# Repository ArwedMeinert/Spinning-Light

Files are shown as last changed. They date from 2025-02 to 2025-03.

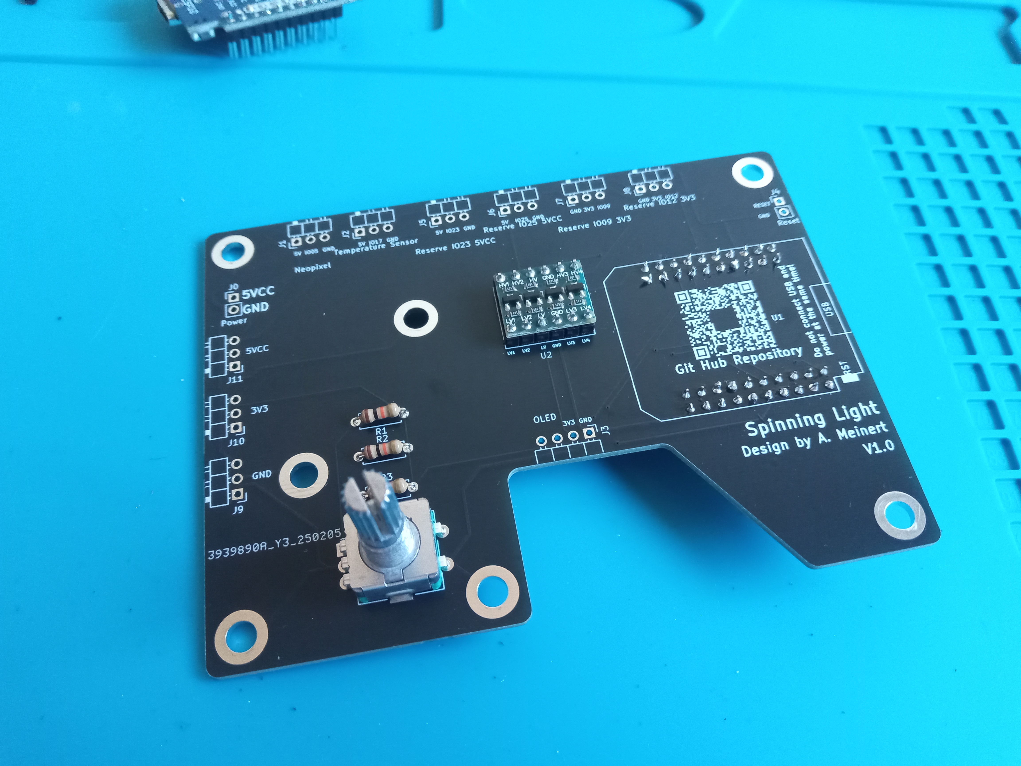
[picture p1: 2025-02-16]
Pictures/PCB with some parts.jpg

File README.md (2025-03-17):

# Spinning Light

___  
This project combines dynamic RGB lighting with a home trainer to enhance your workout experience. The lamp pairs with a power trainer, mapping your power output to its LEDs. The displayed color corresponds to different zones based on your set FTP value. During sprints, the LEDs flash red and yellow to motivate you in your "pain cave."  

All parameters—such as LED brightness, FTP value, and the power trainer’s Bluetooth address—can be adjusted via the GUI. Under **Advanced Settings**, you can modify the zone percentages, LED filter constants, and the number of pixels.  
___  
On the main screen, sensor data for humidity and temperature is displayed. The second page shows the current power output, while the third page displays the Bluetooth address and the power trainer's name.
___
Check out the Youtube Video about the project:

Watch the demo (https://www.youtube.com/watch?v=y7wqykNJxKs)
---

# Microcontroller and Code

The lamp is built around an ESP32 NodeMCU Mini to keep the design compact. The firmware was developed using the Arduino IDE with the ESP32 board definitions (select Node32s). The encoder’s built-in push button is handled without an interrupt, which improves performance and reduces false button detections. A physical pull-up resistor is used, so the internal pull-up is disabled on that pin.

## Connecting Bluetooth

Bluetooth Low Energy (BTLE) is used for connectivity, with the necessary library included in the sketch. Ideally, the device writes the trainer’s address to the EEPROM for automatic reconnection on subsequent startups. However, while the ESP can reconnect automatically after a trainer is initially connected, it does not do so after a restart and must search for the trainer again. Once connected, the ESP subscribes to the power service of the trainer and receives its power data, which is then mapped to LED colors.

---

# Casing

The casing is designed for modularity. Openings for the display, encoder, temperature sensor, and USB port can be finalized after printing. This also allows you to hardcode the Bluetooth address if you prefer not to use the GUI.

Exploded view

---

# PCB



The PCB is designed to work with DuPont connectors for all external components. The ESP is mounted on the back to leave space for the casing lid. The ESP's USB-C port is positioned to allow external access if the plastic cover is removed. The board can be powered either via USB or through the 5V connector located in the left opening. The encoder is mounted directly on the PCB and uses three pull-up resistors—two for rotation detection and one for the push button.

Not all supports need to be screwed in; they primarily help stabilize the push button and prevent the PCB from bending under pressure.



---

# Assembly

The temperature sensor is secured to the left side of the casing. To ensure a proper fit, a section of the lid must be removed to allow the sensor's PCB to protrude. The sensor is mounted using M2 screws, fastened from the outside with a nut on the opposite side. This step should be completed first.

Next, insert the screws into the standoff holes. Use at least four screws to secure the PCB; the remaining standoffs primarily support the encoder’s push button. Once the PCB is fixed within the casing, connect the 5V supply if necessary—or use the USB port for power.



Prepare the lid by removing the sections designated for I/O components (the square for the screen and the circle for the encoder). The OLED screen should be equipped with a DuPont connector and then screwed in place. It doesn't matter whether the screen is mounted on the lid or underneath it; however, if it is mounted below, ensure it is properly supported to avoid damage.

Finally, attach the LED profile to the top, ensuring that the cable is routed into the casing. Depending on the LEDs used, prepare the cables according to the PCB's silkscreen guidelines. Once the lid is modified and the connectors are attached, carefully install the lid to avoid interfering with the sensor and encoder. Finally, secure the lid with screws, and your setup should be operational.



## Bill Of Material (BoM)

<details>
  <summary>Click to expand</summary>

| #  | Reference | Qty | Value | Footprint | DNP |
|----|---|-----|---|---|-----|
| 1  | J0 | 1 | Power | Connector_PinHeader_2.54mm:PinHeader_1x02_P2.54mm_Vertical | |
| 2  | J1 | 1 | Neopixel | Connector_PinHeader_2.54mm:PinHeader_1x03_P2.54mm_Horizontal | |
| 3  | J2 | 1 | Temperature Sensor | Connector_PinHeader_2.54mm:PinHeader_1x03_P2.54mm_Horizontal | |
| 4  | J3 | 1 | OLED | Connector_PinHeader_2.54mm:PinHeader_1x04_P2.54mm_Horizontal | |
| 5  | J4 | 1 | Reset | Connector_PinHeader_2.54mm:PinHeader_1x02_P2.54mm_Vertical | |
| 6  | J5 | 1 | Reserve IO23 5VCC | Connector_PinHeader_2.54mm:PinHeader_1x03_P2.54mm_Horizontal | |
| 7  | J6 | 1 | Reserve IO25 5VCC | Connector_PinHeader_2.54mm:PinHeader_1x03_P2.54mm_Horizontal | |
| 8  | J7 | 1 | Reserve IO09 3V3 | Connector_PinHeader_2.54mm:PinHeader_1x03_P2.54mm_Horizontal | |
| 9  | J8 | 1 | Reserve IO12 3V3 | Connector_PinHeader_2.54mm:PinHeader_1x03_P2.54mm_Horizontal | |
| 10 | J9 | 1 | GND | Connector_PinHeader_2.54mm:PinHeader_1x03_P2.54mm_Horizontal | |
| 11 | J10 | 1 | 3V3 | Connector_PinHeader_2.54mm:PinHeader_1x03_P2.54mm_Horizontal | |
| 12 | J11 | 1 | 5VCC | Connector_PinHeader_2.54mm:PinHeader_1x03_P2.54mm_Horizontal | |
| 13 | R1, R2, R3 | 3 | 10k | Resistor_THT:R_Axial_DIN0207_L6.3mm_D2.5mm_P7.62mm_Horizontal | |
| 14 | SW1 | 1 | RotaryEncoder_Switch | Rotary_Encoder:RotaryEncoder_Alps_EC11E-Switch_Vertical_H20mm | |
| 15 | U1 | 1 | esp32-wemos-d1-mini  | ESP32Mini:esp32-wemos-d1-mini | |
| 16 | U2 | 1 | I2C IIC BiDirektional 5V~3.3V | Level Shifter:4xLevel Shifter | |
| 17 | WS2812 Neopixel  | 1 | WS2812B LED Strip | LED Strip (1m) | |
| 18 | Diffusion Profile| 1 | Aluminium (1m) | LED Diffuser Aluminum Profile | |
| 19 | DHT2302 Sensor | 1 | DHT2302 | Temperature & Humidity Sensor | |
| 20 | OLED Display | 1 | 0.96\" I2C OLED | 128x64 OLED Display Module | |

</details>

### Notes:
- The profile is optional, since the controller can be used with any setup of Neopixel. When used as a standalone lamp, 1m is ideal. The amount of LEDs on the strip are also not set (standart value is 144, but it can be changed under advanced settings)
- **DHT2302**: Temperature and humidity sensor (Optional).
- **OLED display**: 0.96\" I2C screen (128x64 resolution).

---

# Usage

Upon startup, the LEDs display random colors. Pressing the encoder takes you to the menu, where you can adjust the FTP, connect the power trainer, and change the brightness (default is 50%). As you adjust the brightness, a preview gradient is shown—from the Z1 color on the first LED to the Z6 color on the last LED.

Within the menu, pressing the back button returns you to the main screen, which displays the current temperature and humidity, power output, or connected device (selectable via the encoder). A symbol in the top right corner indicates whether the power trainer is connected.

Pressing the button again returns you to the main menu. The final option in the menu is the **Advanced Settings** tab. Here, you can adjust the zone percentages (for example, changing the Z1 zone from 60% of FTP to 70% of FTP), the number of LEDs (default is 144), and the filter constants. The filter provides a gradual transition between LED colors using a low-pass algorithm. The filter constant determines the weight of the most recent power reading; for example, a constant of 0.05 means the new color is calculated as 95% of the previous color and 5% of the new value. Since the LEDs refresh multiple times per second, this results in a smooth color transition.

Similarly, the spark constant controls the number of sparks triggered when exceeding zone Z7. A higher spark constant produces more sparks during sprints, while a lower constant produces fewer sparks. The final option in the Advanced Settings tab resets the configuration data to its default values. Once you change a setting and return to the main screen, the settings are saved to the EEPROM and loaded at each startup—so you only need to configure your FTP, trainer address, brightness, and other settings once.

---

# Limitations and Improvements

- **Bluetooth Channels:**  
  ~~The lamp only works with trainers that support at least two Bluetooth channels.~~ It is only possible to connect the lamp and Zwift via bluetooth if the power trainer supports two bluetooth cahannels. It is however possible to connect Zwift via ANT+ and the lamp via BTLE (virtual shifting does not work in this case). I have tested the bluetooth connection with the Wahoo KickrCore and the Zwift Hub. Since the Wahoo KickrCore works, I suspect it will also work with other Wahoo power trainers, although I have not tested them. I welcome any additional information on this topic. See the table below.

- **Automatic Connection Issue:**  
  For some reason, upon startup the microcontroller does not automatically connect to the power trainer, even though the saved address appears to be correct. Manual connection works without issue, and the device reconnects if the power trainer loses power. Despite saving the address in the configuration data, automatic reconnection does not function as expected. I have tried scanning and multiple connection attempts at startup without success. The current workaround is to avoid powering off the lamp (as it consumes minimal power). Any advice on resolving this issue would be greatly appreciated.

- **UI Responsiveness:**  
  At times, the user interface may feel somewhat sluggish, particularly when the encoder is turned rapidly. I suspect this is primarily due to the inexpensive encoder, though other factors may contribute. Turning the encoder slowly generally results in smooth operation.

---

# Known Compatible Power Trainers with Two BT Channels

| Works | Does Not Work |
|---|---|
| Wahoo KickrCore | Zwift Hub/Hub One |

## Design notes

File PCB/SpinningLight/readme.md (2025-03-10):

# PCB 
The PCB makes the wirering easier and allows for easy attatchment of additional sensors. The PCB was created using KiCAD 7.0 and this path includes all files to order and modify the files at hand. 

## Additional Modifications
The PCB already has lanes to multiple GPIO pins of the ESP, allowing easy modification and expansion with more sensor. Some inputs use the additional unused channels of the Level shifter.

___


___



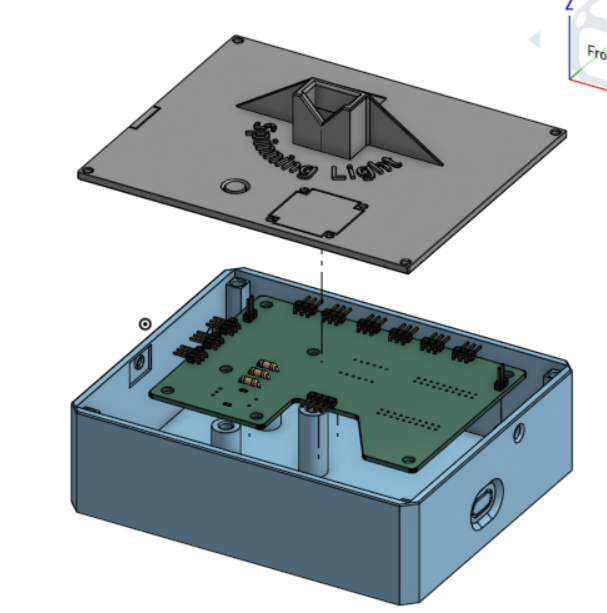
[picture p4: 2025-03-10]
Pictures/Exploded view.png

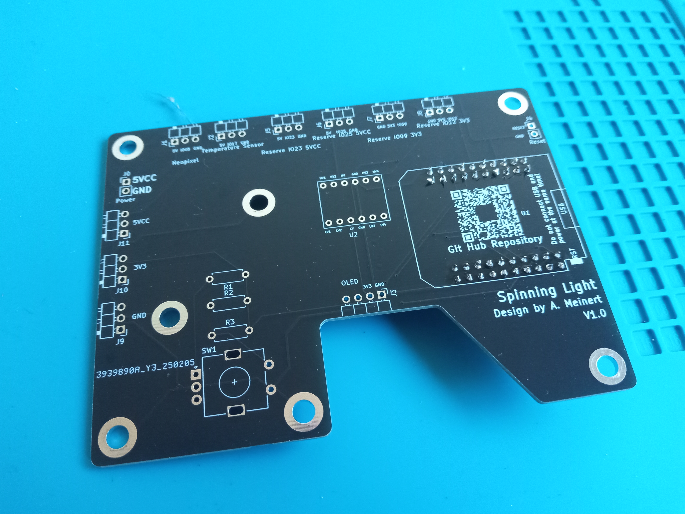
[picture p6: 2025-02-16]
Pictures/Just PCB.jpg

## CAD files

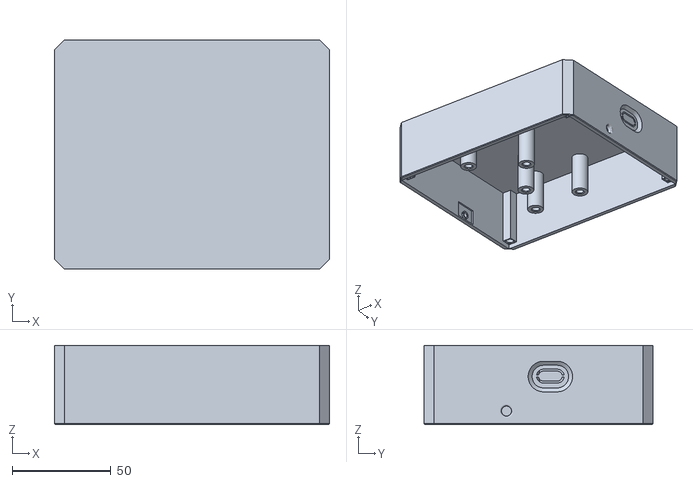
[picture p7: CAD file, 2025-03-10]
Casing/Assembly/Assembly 1 - Bottom.stl
139.2 x 116.0 x 40.0

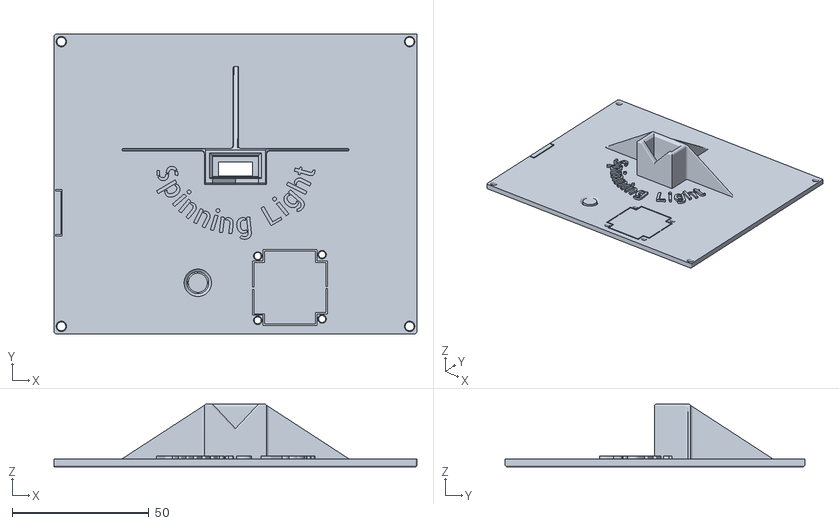
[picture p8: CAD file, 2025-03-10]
Casing/Assembly/Assembly 1 - Lid.stl
132.6 x 109.4 x 23.0

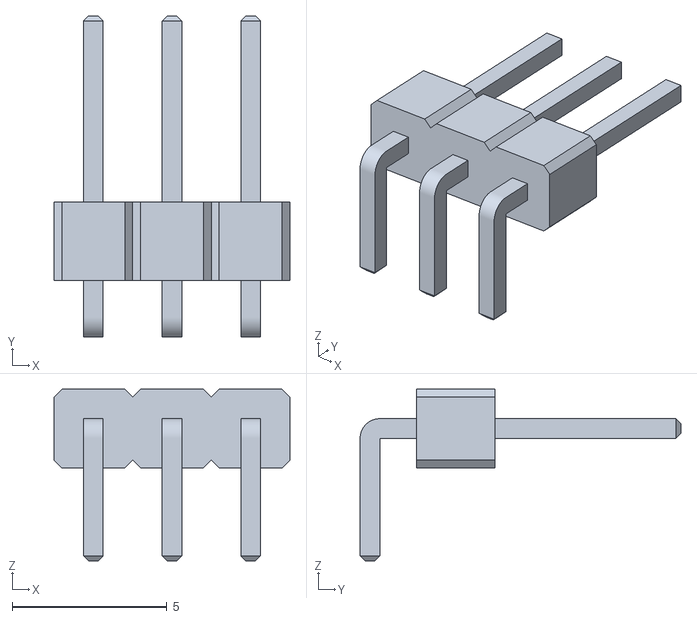
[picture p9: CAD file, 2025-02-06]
Casing/Assembly/Assembly 1 - SOLID_6.stl
7.62 x 10.4 x 5.54

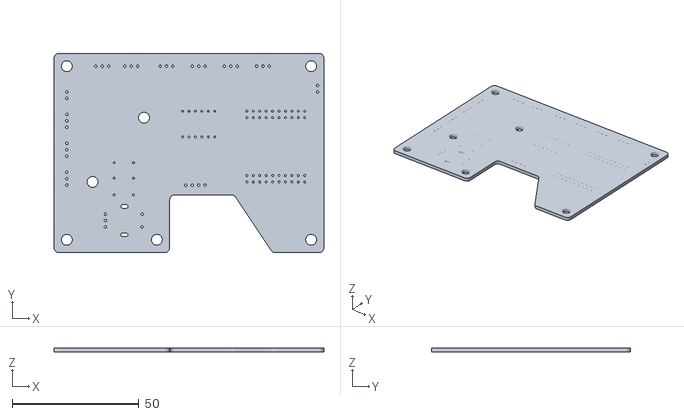
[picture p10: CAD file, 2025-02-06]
Casing/Assembly/Assembly 1 - SpinningLight PCB.stl
106.7 x 78.7 x 1.60

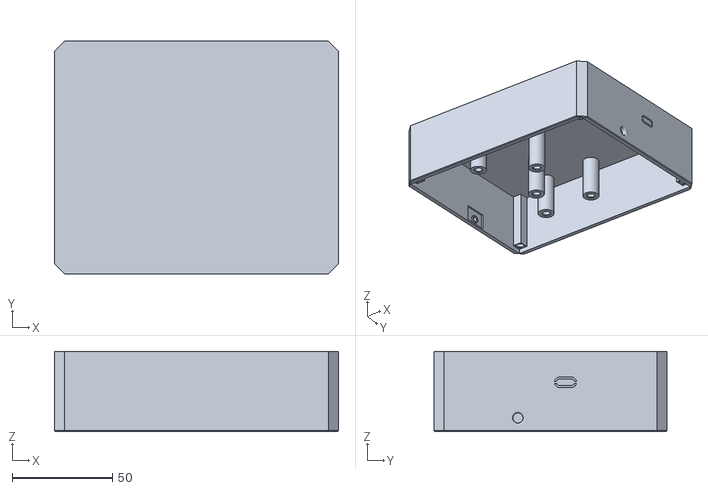
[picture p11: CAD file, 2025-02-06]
Casing/Bottom.stl
141.5 x 116.0 x 40.0

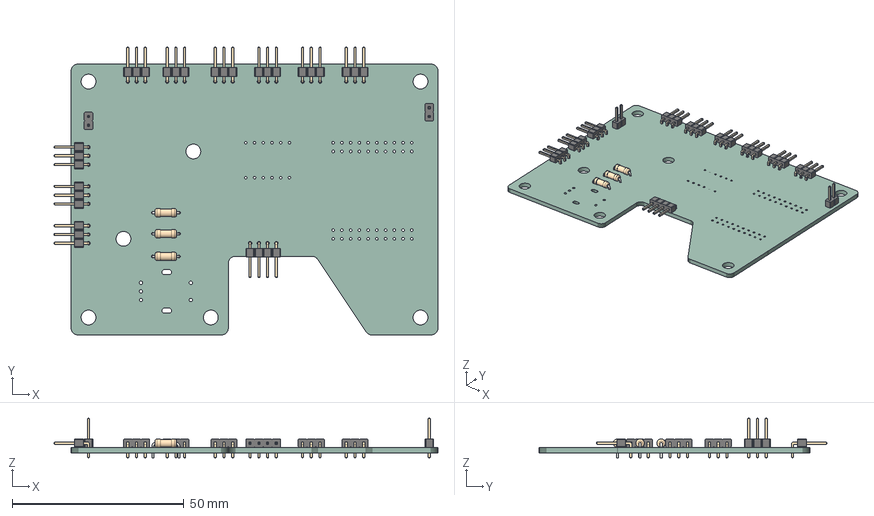
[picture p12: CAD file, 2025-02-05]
PCB/SpinningLight/SpinningLight.step
111.6 x 83.7 x 11.5 mm
SpinningLight PCB

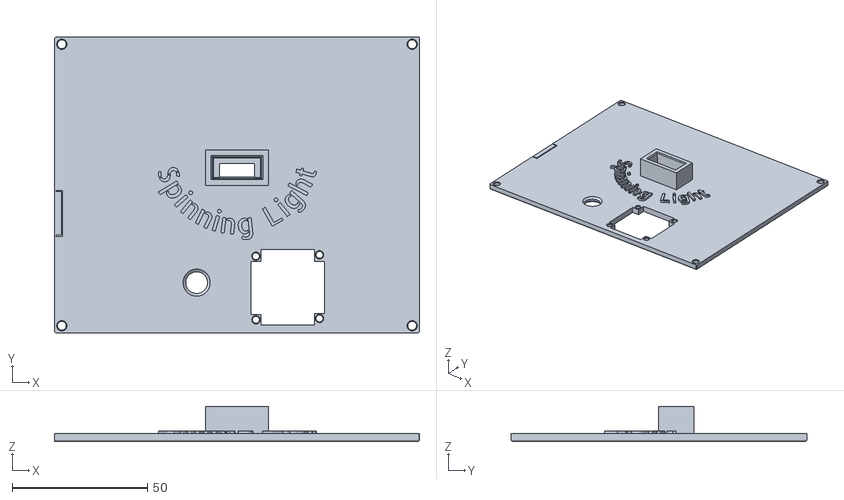
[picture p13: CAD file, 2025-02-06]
Casing/Lid.stl
134.9 x 109.4 x 13.0

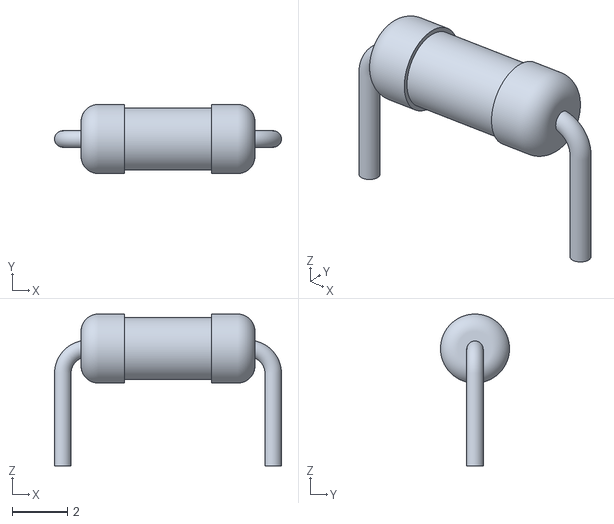
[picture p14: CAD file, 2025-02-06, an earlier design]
Casing/Assembly/Assembly 1 - SOLID_1 (1).stl
8.22 x 2.50 x 5.50

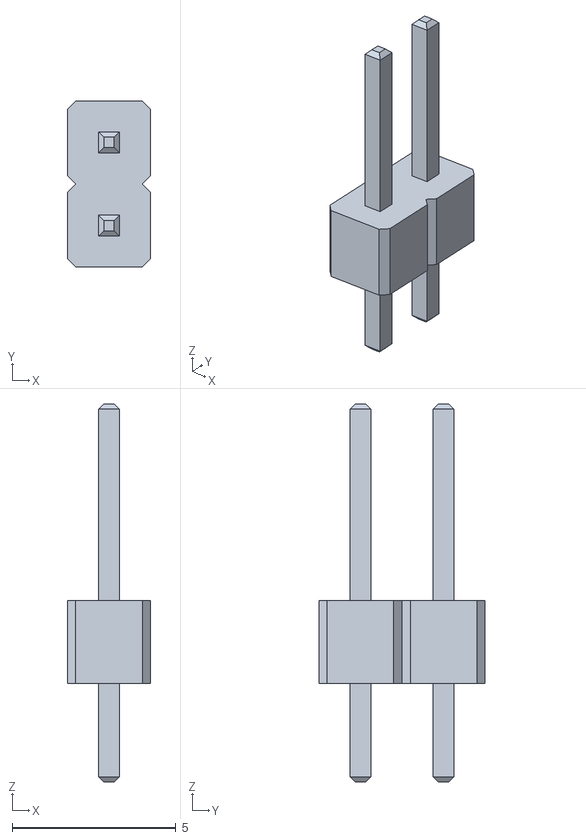
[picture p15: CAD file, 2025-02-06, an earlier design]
Casing/Assembly/Assembly 1 - SOLID (2).stl
2.54 x 5.08 x 11.5

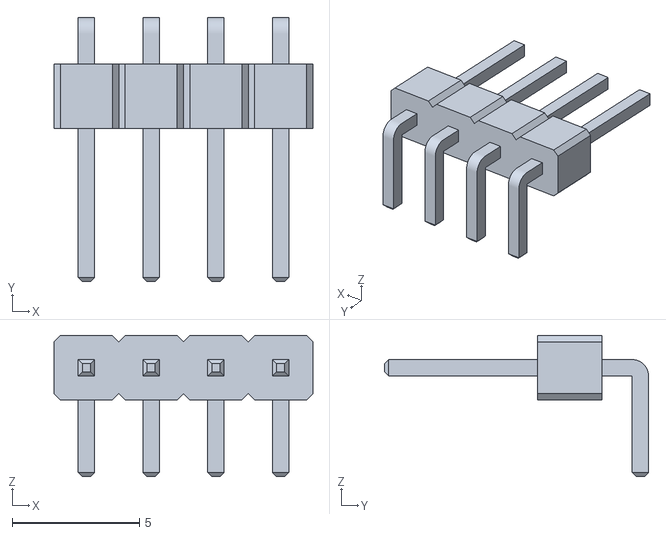
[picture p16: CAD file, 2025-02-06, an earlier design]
Casing/Assembly/Assembly 1 - SOLID (3).stl
10.2 x 10.4 x 5.54

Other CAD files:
Casing/Assembly/Assembly 1 - SOLID.stl
Casing/Assembly/Assembly 1 - SOLID_7.stl
Casing/Assembly/Assembly 1 - SOLID_5.stl
Casing/Assembly/Assembly 1 - SOLID_4.stl
Casing/Assembly/Assembly 1 - SOLID_8.stl
Casing/Assembly/Assembly 1 - SOLID_2 (1).stl
Casing/Assembly/Assembly 1 - SOLID (1).stl
Casing/Assembly/Assembly 1 - SOLID_1 (2).stl
Casing/Assembly/Assembly 1 - SOLID_1.stl
Casing/Assembly/Assembly 1 - SOLID_2.stl
Casing/Assembly/Assembly 1 - SOLID_3.stl

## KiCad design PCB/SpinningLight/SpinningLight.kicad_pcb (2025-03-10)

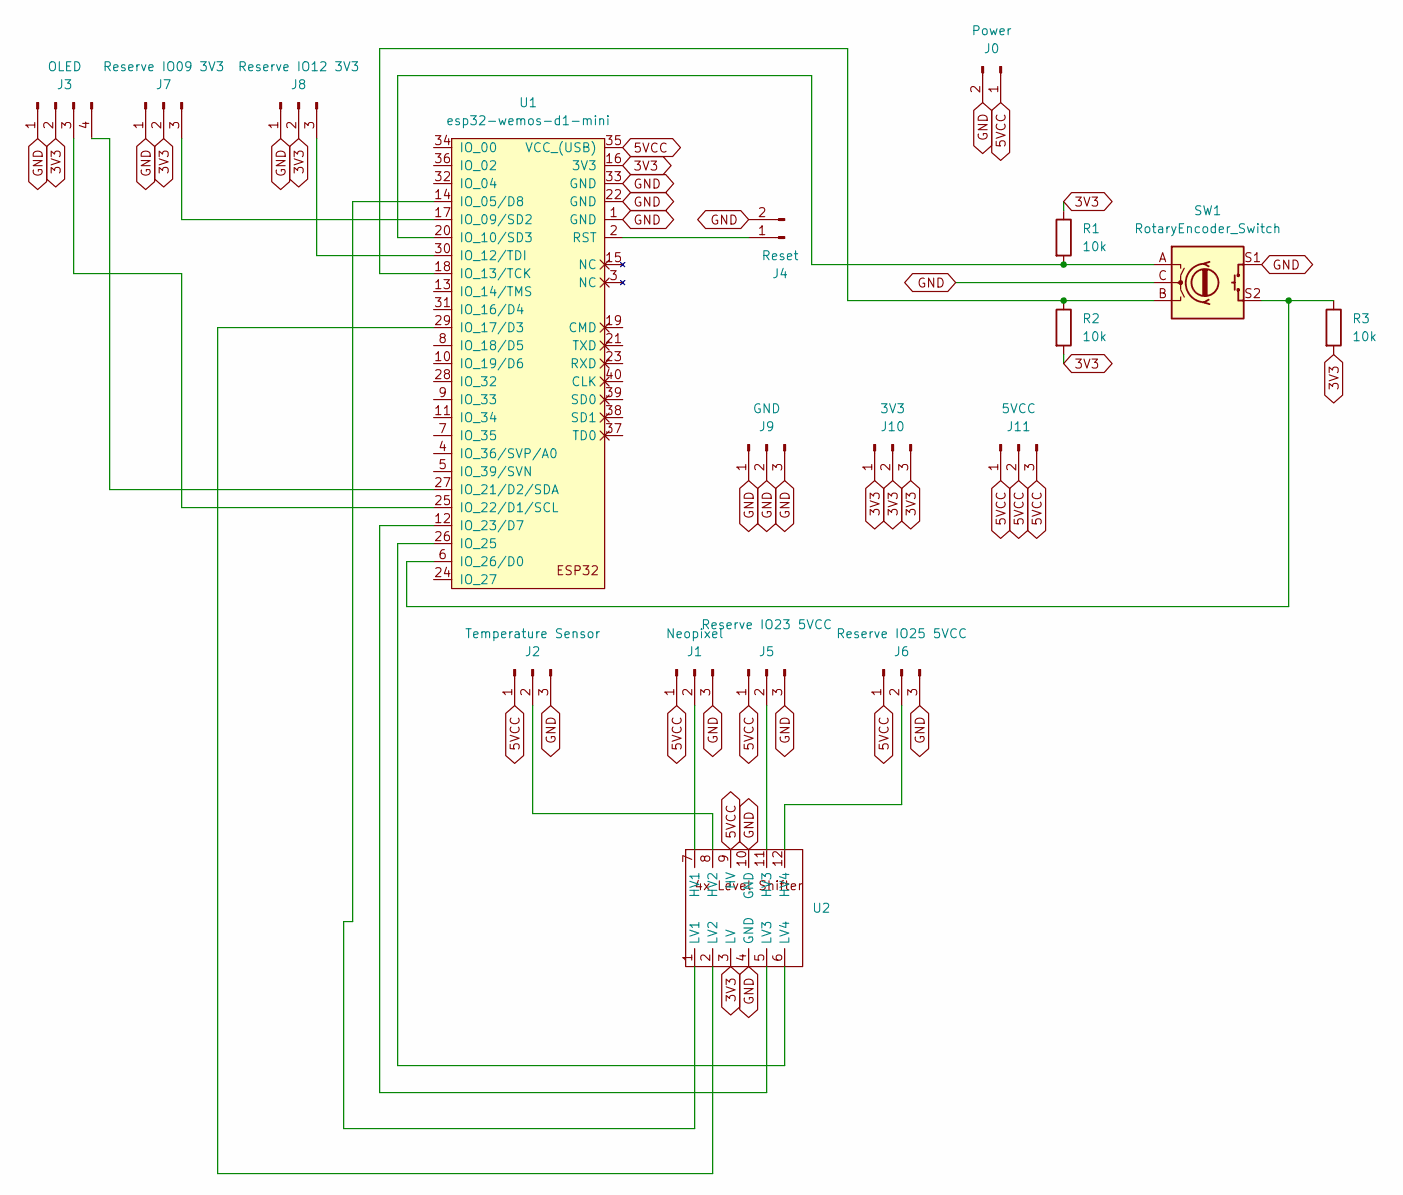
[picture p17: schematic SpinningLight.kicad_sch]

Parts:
J0: Power; PinHeader_1x02_P2.54mm_Vertical
J1: Neopixel; PinHeader_1x03_P2.54mm_Horizontal
J2: Temperature Sensor; PinHeader_1x03_P2.54mm_Horizontal
J3: OLED; PinHeader_1x04_P2.54mm_Horizontal
J4: Reset; PinHeader_1x02_P2.54mm_Vertical
J5: Reserve IO23 5VCC; PinHeader_1x03_P2.54mm_Horizontal
J6: Reserve IO25 5VCC; PinHeader_1x03_P2.54mm_Horizontal
J7: Reserve IO09 3V3; PinHeader_1x03_P2.54mm_Horizontal
J8: Reserve IO12 3V3; PinHeader_1x03_P2.54mm_Horizontal
J9: GND; PinHeader_1x03_P2.54mm_Horizontal
J10: 3V3; PinHeader_1x03_P2.54mm_Horizontal
J11: 5VCC; PinHeader_1x03_P2.54mm_Horizontal
R1, R2, R3: 10k; R_Axial_DIN0207_L6.3mm_D2.5mm_P7.62mm_Horizontal
SW1: RotaryEncoder_Switch; RotaryEncoder_Alps_EC11E-Switch_Vertical_H20mm
U1: esp32-wemos-d1-mini
U2: 4xLEvel Shifter

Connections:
3V3: J3.2, J7.2, J8.2, J10.1, J10.2, J10.3, R1.1, R2.2, R3.2, U1.16 (3V3), U2.3 (LV)
5VCC: J0.1, J1.1, J2.1, J5.1, J6.1, J11.1, J11.2, J11.3, U1.35 (VCC_(USB)), U2.9 (HV)
GND: J0.2, J1.3, J2.3, J3.1, J4.2, J5.3, J6.3, J7.1, J8.1, J9.1, J9.2, J9.3, SW1.C, SW1.S1, U1.1 (GND), U1.22 (GND), U1.33 (GND), U2.4 (GND), U2.10 (GND)
unnamed: J1.2, U2.7 (HV1)
unnamed: J2.2, U2.8 (HV2)
unnamed: J3.3, U1.25 (IO_22/D1/SCL)
unnamed: J3.4, U1.27 (IO_21/D2/SDA)
unnamed: J4.1, U1.2 (RST)
unnamed: J5.2, U2.11 (HV3)
unnamed: J6.2, U2.12 (HV4)
unnamed: J7.3, U1.17 (IO_09/SD2)
unnamed: J8.3, U1.30 (IO_12/TDI)
unnamed: U1.14 (IO_05/D8), U2.1 (LV1)
unnamed: R1.2, SW1.A, U1.20 (IO_10/SD3)
unnamed: R2.1, SW1.B, U1.18 (IO_13/TCK)
unnamed: U1.29 (IO_17/D3), U2.2 (LV2)
unnamed: U1.12 (IO_23/D7), U2.5 (LV3)
unnamed: U1.26 (IO_25), U2.6 (LV4)
unnamed: R3.1, SW1.S2, U1.6 (IO_26/D0)

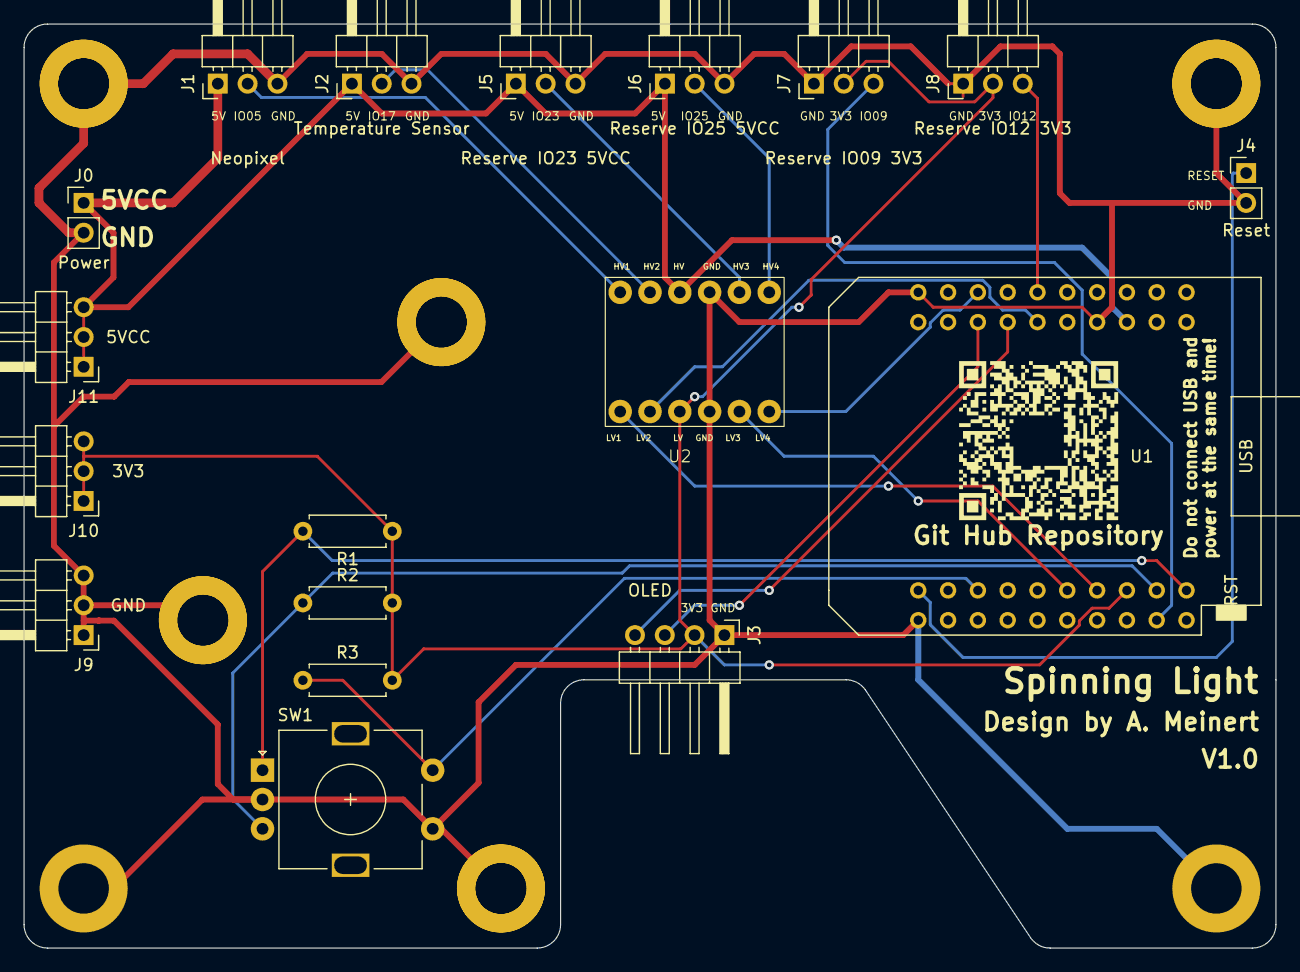
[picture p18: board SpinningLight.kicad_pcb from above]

Board: 2 copper layers, 106.7 x 78.7 mm, 18 parts (0 on the bottom side), 19 nets.

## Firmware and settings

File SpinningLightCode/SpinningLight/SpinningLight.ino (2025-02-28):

#include <SPI.h>
#include <Wire.h>
#include <Adafruit_GFX.h>
#include <Adafruit_SSD1306.h>
#include <AM2302-Sensor.h>
#include <Encoder.h>
#include <FastLED.h>
#include <EEPROM.h>
#include <Arduino.h>
#include <FunctionalInterrupt.h>

#include <BLEDevice.h>
#include <BLEUtils.h>
#include <BLEClient.h>
#include <BLEScan.h>
#include <BLEAdvertisedDevice.h>
#include <BLEEddystoneURL.h>
#include <BLEEddystoneTLM.h>
#include <BLEBeacon.h>
#include <BLE2902.h>



struct Config {
    uint32_t magicNumber = 0xA5A5A5A5;  // Identifier for validity
    int ftp = 100;
    float brightness = 0.5;
    char bt_name[20]="No Device";
    char bt_adress[20] = "00:00:00:00"; // Changed to char array for compatibility
    int num_pixel = 144;
    bool temperature_sensor = true;
    bool first_start = true;
    float z1_percentage = 0.6;
    float z2_percentage = 0.75;
    float z3_percentage = 0.9;
    float z4_percentage = 1.05;
    float z5_percentage = 1.2;
    float z6_percentage = 1.3;
    float filter_constant = 0.05;
    float spark_constant = 0.38;
};


Config configDefault; // Default configuration
Config configData;    // Active configuration
Config configDataBackup; // Backup for changes




// GUI
enum Mode { NORMAL, SELECT, ADJUST,BTSCAN,STARTUP };
Mode currentMode = NORMAL;
int selectedVariable = 0;    // Index of the currently selected variable
bool inAdvancedTab = false;  // Track if the advanced tab is selected
int scrollOffset = 0;        // Tracks the starting index of the visible menu items
int mainPage=0;
const int MAX_VISIBLE_ITEMS = 4; // Number of items to show at a time
const uint8_t checkMark[] = {
  0x3C, 0x42, 0x42, 0x42, 0x3C // Custom checkmark bitmap (5x5)
};

const uint8_t crossMark[] = {
  0x42, 0x42, 0x42, 0x42, 0x42 // Custom cross bitmap (5x5)
};


// Encoder
Encoder myEnc(10, 13);
long oldPosition = -999;
bool isButtonPressed = false;
long lastUpdateMillis = 0;
const int ENCODER_STEP_THRESHOLD = 3;  // Set the number of steps needed before an action is taken

// Neopixel
#define PIN        5 // On Trinket or Gemma, suggest changing this to 1
CRGB* leds = nullptr;
uint8_t currentPixelCount = 0;
//Colours
CRGB off=CRGB(0,0,0);
CRGB z1_colour=CRGB(255,255,255); //white
CRGB z2_colour=CRGB(0,0,255); //blue
CRGB z3_colour=CRGB(0,255,0); //green
CRGB z4_colour=CRGB(255,255,0); // yellow
CRGB z5_colour=CRGB(255,130,0); //orange
CRGB z6_colour=CRGB(255,0,0); // red
CRGB z7_colour=CRGB(255,0,255); //purple
float zone1_middle;
float zone2_middle;
float zone3_middle;
float zone4_middle;
float zone5_middle;
float zone6_middle;
float zone7_start;
float power;
float prevPower;

// OLED
#define SCREEN_WIDTH 128  // OLED display width, in pixels
#define SCREEN_HEIGHT 64  // OLED display height, in pixels
#define OLED_RESET -1     // Reset pin # (or -1 if sharing Arduino reset pin)
#define SCREEN_ADDRESS 0x3C // I2C address for the display
#define SDA_PIN 21
#define SCL_PIN 22
Adafruit_SSD1306 display(SCREEN_WIDTH, SCREEN_HEIGHT, &Wire, OLED_RESET);
static const unsigned char PROGMEM image_wifi_not_connected_bits[] = {0x21,0xf0,0x00,0x16,0x0c,0x00,0x08,0x03,0x00,0x25,0xf0,0x80,0x42,0x0c,0x40,0x89,0x02,0x20,0x10,0xa1,0x00,0x23,0x58,0x80,0x04,0x24,0x00,0x08,0x52,0x00,0x01,0xa8,0x00,0x02,0x04,0x00,0x00,0x42,0x00,0x00,0xa1,0x00,0x00,0x40,0x80,0x00,0x00,0x00};
static const unsigned char PROGMEM image_wifi_full_bits[] = {0x01,0xf0,0x00,0x07,0xfc,0x00,0x1e,0x0f,0x00,0x39,0xf3,0x80,0x77,0xfd,0xc0,0xef,0x1e,0xe0,0x5c,0xe7,0x40,0x3b,0xfb,0x80,0x17,0x1d,0x00,0x0e,0xee,0x00,0x05,0xf4,0x00,0x03,0xb8,0x00,0x01,0x50,0x00,0x00,0xe0,0x00,0x00,0x40,0x00,0x00,0x00,0x00};


// AM2302 Sensor
AM2302::AM2302_Sensor am2302(17); // Replace '0' with the correct pin connected to the sensor
int status = -1;

//BTLE
BLEClient* client;
BLEScan* pBLEScan;
int scanTime=3;
int deviceCount = 0;
const int MAX_DEVICES = 10;
bool connected=false;
BLEAdvertisedDevice foundDevices[MAX_DEVICES]; // Use pointers to manage memory
static BLEUUID serviceUUID("1818");  // Power Service UUID (16-bit)
static BLEUUID charUUID("2A63");

void notifyCallback(BLERemoteCharacteristic* characteristic, uint8_t* data, size_t length, bool isNotify) {
  if (length >= 4) {
    // Parse the power value (Watts)
    uint16_t power_measurement = data[2] | (data[3] << 8);
    Serial.print("Power: ");
    Serial.print(power_measurement);
    prevPower=power;
    power=power_measurement;
    Serial.println(" W");
  }
}


class MyAdvertisedDeviceCallbacks : public BLEAdvertisedDeviceCallbacks {
  void onResult(BLEAdvertisedDevice advertisedDevice) override {
  if (deviceCount < MAX_DEVICES && advertisedDevice.getName() != "" && advertisedDevice.isAdvertisingService(serviceUUID)) {
    foundDevices[deviceCount] = advertisedDevice; // Store by value
    deviceCount++;
  }
}
};

class MyClientCallback : public BLEClientCallbacks {
  void onConnect(BLEClient *pclient) {}

  void onDisconnect(BLEClient *pclient) {
    connected = false;
    Serial.println("onDisconnect");
  }
};

void ARDUINO_ISR_ATTR handleKey() {
  detachInterrupt(26);
    isButtonPressed = true;
}

bool connecting_bt(){
  display.clearDisplay();
  display.setTextSize(2.5);             // Normal 1:1 pixel scale
  display.setTextColor(SSD1306_WHITE);  // Draw white text
  display.setCursor(0,0) ;
  display.print("Connecting");
  display.setCursor(0,int(SCREEN_HEIGHT/2) );
  display.print("Device");
  display.display();
  delay(1000);
  client = BLEDevice::createClient();
  BLEAddress deviceAddress(configData.bt_adress); // Replace with your device's MAC address
    Serial.println(deviceAddress.toString());
  
  client->setClientCallbacks(new MyClientCallback());
  delay(200);
  if (!client->connect(deviceAddress)) {
    Serial.println("Failed to connect to the power trainer.");
    
    return false;
  }
  Serial.println("Connected to power trainer!");
// Access the Power Service
  display.clearDisplay();
  display.setTextSize(2.5);             // Normal 1:1 pixel scale
  display.setTextColor(SSD1306_WHITE);  // Draw white text
  display.setCursor(0,0) ;
  display.print("Connecting");
  display.setCursor(0,int(SCREEN_HEIGHT/2) );
  display.print("Power Service");
  display.display();
  BLERemoteService *powerService = client->getService(serviceUUID);
if (powerService == nullptr) {
    Serial.print("Failed to find our service UUID: ");
    Serial.println(serviceUUID.toString().c_str());
    client->disconnect();
    return false;
  }

// Step 3: Access the Power Measurement Characteristic from the service
display.clearDisplay();
display.setTextSize(2.5);             // Normal 1:1 pixel scale
display.setTextColor(SSD1306_WHITE);  // Draw white text
display.setCursor(0, 0);
display.print("Access");
display.setCursor(0, int(SCREEN_HEIGHT / 2));
display.print("Power");
display.display();

BLERemoteCharacteristic* powerCharacteristic = powerService->getCharacteristic(charUUID);
if (powerCharacteristic == nullptr) {
    Serial.print("Failed to find our characteristic UUID: ");
    Serial.println(charUUID.toString().c_str());
    client->disconnect();
    return false;
  }
// Register the notify callback
powerCharacteristic->registerForNotify(notifyCallback);
  
Serial.println("Subscribed to power updates.");
return true;
}





void calculateZones(){
float ftp=configData.ftp;
zone1_middle=(ftp*configData.z1_percentage)/2;
zone2_middle=(ftp*configData.z1_percentage)+((ftp*configData.z2_percentage)-(ftp*configData.z1_percentage))/2;
zone3_middle=(ftp*configData.z2_percentage)+((ftp*configData.z3_percentage)-(ftp*configData.z2_percentage))/2;
zone4_middle=(ftp*configData.z3_percentage)+((ftp*configData.z4_percentage)-(ftp*configData.z3_percentage))/2;
zone5_middle=(ftp*configData.z4_percentage)+((ftp*configData.z5_percentage)-(ftp*configData.z4_percentage))/2;
zone6_middle=(ftp*configData.z5_percentage)+((ftp*configData.z6_percentage)-(ftp*configData.z5_percentage))/2;
zone7_start=(ftp*configData.z6_percentage)+((ftp*configData.z6_percentage)-(ftp*configData.z5_percentage))/2;
}

CRGB blendColors(CRGB color1, CRGB color2, float ratio) {
    // Clamp ratio to the range 0.0 to 1.0
    ratio = constrain(ratio, 0.0, 1.0);

    // Linearly interpolate each RGB component
    return CRGB(
        (1 - ratio) * color1.r + ratio * color2.r,
        (1 - ratio) * color1.g + ratio * color2.g,
        (1 - ratio) * color1.b + ratio * color2.b
    );
}

void showPower(){
  bool rising=(power>prevPower);
  CRGB newColor;
  float filterConst=configData.filter_constant;
  float sparkConst=configData.spark_constant;

if (power<zone1_middle){
  newColor=blendColors(off,z1_colour,1-(zone1_middle-power)/zone1_middle);
} else if (power>zone1_middle && power <zone2_middle){
   newColor=blendColors(z1_colour,z2_colour,1-(zone2_middle-power)/(zone2_middle-zone1_middle));
}else if (power>zone2_middle && power <zone3_middle){
   newColor=blendColors(z2_colour,z3_colour,1-(zone3_middle-power)/(zone3_middle-zone2_middle));
}else if (power>zone3_middle && power <zone4_middle){
   newColor=blendColors(z3_colour,z4_colour,1-(zone4_middle-power)/(zone4_middle-zone3_middle));
}else if (power>zone4_middle && power <zone5_middle){
   newColor=blendColors(z4_colour,z5_colour,1-(zone5_middle-power)/(zone5_middle-zone4_middle));
}else if (power>zone5_middle && power <zone6_middle){
   newColor=blendColors(z5_colour,z6_colour,1-(zone6_middle-power)/(zone6_middle-zone5_middle));
}else if (power>zone6_middle){
   newColor=blendColors(z6_colour,z7_colour,1-(zone7_start-power)/(zone7_start-zone6_middle));
}else if (power>zone7_start){
   newColor=z7_colour;
}


if (rising) {
    for (int i = 0; i < currentPixelCount; i++) {
        leds[i] = blendColors(leds[i], newColor, filterConst * (currentPixelCount - i) / currentPixelCount);
    }
} else {
    for (int i = 0; i < currentPixelCount; i++) {
        leds[i] = blendColors(leds[i], newColor, (filterConst * i+1) / currentPixelCount);
    }
}

if (power > zone6_middle) {
    // Calculate the upper limit for randomizing the number of pixels
    float powerAboveThreshold = power - zone6_middle;
    int maxRandomPixels = map(powerAboveThreshold, 0, configData.ftp * 3, 1, currentPixelCount) * sparkConst+0.5; 

    // Generate a random number of pixels to change
    int numRandomPixels = random(0, maxRandomPixels + 1); // Ensure at least 1 pixel changes

    for (int i = 0; i < numRandomPixels; i++) {
        // Choose a random pixel index
        int randomIndex = random(0, currentPixelCount);
        
        // Set the pixel to either red or yellow
        if (random(0, 2) == 0) {
            leds[randomIndex] = CRGB::Red;
        } else {
            leds[randomIndex] = CRGB::Yellow;
        }
    }
}
FastLED.show();
}

void saveConfiguration() {
    // Write the configuration to EEPROM
    int address = 0;
    EEPROM.writeBytes(address, &configData, sizeof(Config));
    EEPROM.commit();
    Serial.println("Configuration saved to EEPROM.");
}

void loadConfiguration() {
    int address = 0;
    Config tempConfig;

    // Read the configuration from EEPROM
    EEPROM.readBytes(address, &tempConfig, sizeof(Config));

    // Check for a valid magic number
    if (tempConfig.magicNumber == 0xA5A5A5A5) {
        configData = tempConfig;
        Serial.println("Loaded configuration from EEPROM.");
    } else {
        Serial.println("No valid configuration found. Initializing defaults...");
        initializeDefaultConfig();
    }

    // Backup the loaded configuration
    configDataBackup = configData;
}

void initializeDefaultConfig() {
    configData = configDefault; // Load default settings
    saveConfiguration();        // Save to EEPROM
}

void writeBT( int x_pos, int y_pos) {
  display.setTextSize(2);             // Normal 1:1 pixel scale
  display.setTextColor(SSD1306_WHITE);  // Draw white text
  display.setCursor(x_pos, y_pos);     // Start at specified position


  // Display BT address and BT name from configData

  display.println("Addr:");
  display.setTextSize(1);
  display.println(configData.bt_adress);  // Display BT address
display.setTextSize(2);
  display.println("Name:");
  display.setTextSize(1);
  display.println(configData.bt_name);  // Display BT name
  // Display Bluetooth connection status symbol in top-right corner

  display.setCursor(SCREEN_WIDTH - 24, 0); // Position it at top-right corner (16 pixels for the symbol size)

  if (connected) {
    display.drawBitmap(108.5, 1, image_wifi_full_bits, 19, 16, 1);
  } else {
    display.drawBitmap(109, 0, image_wifi_not_connected_bits, 19, 16, 1);
    
  }
}


void writeData(float temperature, float humidity, int x_pos, int y_pos) {
  display.setTextSize(3);             // Normal 1:1 pixel scale
  display.setTextColor(SSD1306_WHITE);  // Draw white text
  display.setCursor(x_pos, y_pos);     // Start at specified position
if (configData.temperature_sensor){
  // Display temperature and humidity
  display.print("T:");
  display.println(String(temperature, 1));
//display.setCursor(0, 24);
  display.print("H:");
  display.print(String(humidity, 0));
  display.println(" %");

} else {
  display.setTextSize(2);
  display.println("Temperature Sensor");
  display.println("tuned Off");
}
  display.setCursor(SCREEN_WIDTH - 20, 0); // Position it at top-right corner (16 pixels for the symbol size)
display.setTextSize(1);
  if (connected) {
    display.drawBitmap(108.5, 1, image_wifi_full_bits, 19, 16, 1);
  } else {
    display.drawBitmap(109, 0, image_wifi_not_connected_bits, 19, 16, 1);
    
  }
}
void writePower(int x_pos, int y_pos) {
  display.setTextSize(2);             // Normal 1:1 pixel scale
  display.setTextColor(SSD1306_WHITE);  // Draw white text
  display.setCursor(x_pos, y_pos);     // Start at specified position
  // Display temperature and humidity
  display.println("Power:");
display.setCursor(0, 16);
  display.print(String(power));
  display.println(" W");

  display.setCursor(SCREEN_WIDTH - 24, 0); // Position it at top-right corner (16 pixels for the symbol size)

  if (connected) {
    display.drawBitmap(108.5, 1, image_wifi_full_bits, 19, 16, 1);
  } else {
    display.drawBitmap(109, 0, image_wifi_not_connected_bits, 19, 16, 1);
    
  }
}
void initializeFastLED() {
    // Cleanup the previous LED array if it exists
    if (leds != nullptr) {
        delete[] leds;
        leds = nullptr;
    }

    // Allocate new LED array based on configData.num_pixel
    currentPixelCount = configData.num_pixel;
    leds = new CRGB[currentPixelCount];

    // Set up FastLED with the new configuration
    FastLED.addLeds<WS2812, PIN, GRB>(leds, currentPixelCount);
    FastLED.setBrightness(int(configData.brightness * 255));

    // Clear LEDs on initialization
    FastLED.clear();
    FastLED.show();
}



void drawPixels() {
  FastLED.clear();

  // Map pixel indices to a power value between zone1_middle and zone6_middle.
  // (Make sure calculateZones() has already been called so that these values are set.)
  for (int i = 0; i < currentPixelCount; i++) {
    // Compute a value along the power range. The first pixel will correspond to zone1_middle,
    // the last pixel to zone6_middle.
    float mappedValue = zone1_middle + (zone7_start-zone1_middle) * (i / float(currentPixelCount - 1));
    CRGB color;

    // Decide which zone segment this mapped value falls into and blend accordingly.
    if (mappedValue <= zone2_middle) {
      // Between zone 1 and zone 2.
      float ratio = (mappedValue - zone1_middle) / (zone2_middle - zone1_middle);
      color = blendColors(z1_colour, z2_colour, ratio);
    } else if (mappedValue <= zone3_middle) {
      // Between zone 2 and zone 3.
      float ratio = (mappedValue - zone2_middle) / (zone3_middle - zone2_middle);
      color = blendColors(z2_colour, z3_colour, ratio);
    } else if (mappedValue <= zone4_middle) {
      // Between zone 3 and zone 4.
      float ratio = (mappedValue - zone3_middle) / (zone4_middle - zone3_middle);
      color = blendColors(z3_colour, z4_colour, ratio);
    } else if (mappedValue <= zone5_middle) {
      // Between zone 4 and zone 5.
      float ratio = (mappedValue - zone5_middle) / (zone6_middle - zone5_middle);
      color = blendColors(z4_colour, z5_colour, ratio);
    }  else if (mappedValue <= zone6_middle){
    // Between zone 4 and zone 5.
      float ratio = (mappedValue - zone6_middle) / (zone7_start - zone6_middle);
      color = blendColors(z6_colour, z7_colour, ratio);
    }else {
      color = z7_colour;
    }

    leds[i] = color;
    Serial.println(i);
  }
  FastLED.show();
}

void greetUser() {
  currentMode=STARTUP;
  display.clearDisplay();
  display.setTextSize(2);
  display.setTextColor(SSD1306_WHITE);
  display.setCursor(10, 10);
  display.println("Welcome!");

  display.setTextSize(1);
  display.setCursor(10, 30);
  display.println("Press the button");

  display.display();  // Refresh the screen

  // Make the LEDs glow in random colors
  for (int i = 0; i < currentPixelCount; i++) {
    leds[i] = CRGB(random(0, 255), random(0, 255), random(0, 255));  // Random RGB color
  }
  FastLED.show();
}



void drawMenu() {
  display.clearDisplay();
  display.setTextSize(1);
  display.setTextColor(SSD1306_WHITE);

  if (!inAdvancedTab) {
    const char *menuItems[] = {"Normal Mode", "FTP", "Brightness", "BT Address", "Advanced Settings"};
    for (int i = 0; i < 5; i++) {
      if (i == selectedVariable) display.setTextColor(SSD1306_BLACK, SSD1306_WHITE);
      else display.setTextColor(SSD1306_WHITE);

      display.setCursor(0, i * 10);
      display.print(menuItems[i]);
    }
  } else {
    const char *advMenuItems[] = {
      "Back", "Num Pixels", "Temp Sensor", "Z1 Percentage",
      "Z2 Percentage", "Z3 Percentage", "Z4 Percentage",
      "Z5 Percentage", "Z6 Percentage", "Filter Const",
      "Spark Const", "Reset"
    };

    for (int i = 0; i < MAX_VISIBLE_ITEMS; i++) {
      int index = i + scrollOffset;
      if (index >= 12) break;

      if (index == selectedVariable) display.setTextColor(SSD1306_BLACK, SSD1306_WHITE);
      else display.setTextColor(SSD1306_WHITE);

      display.setCursor(0, i * 10);
      display.print(advMenuItems[index]);
    }
  }

  display.display();
}


void adjustVariable() {
  display.clearDisplay();
  display.setTextSize(1);
  display.setTextColor(SSD1306_WHITE);

  display.setCursor(0, 0);
  
  // Display different menu depending on whether we're in the advanced tab
  if (!inAdvancedTab) {
    const char *menuItems[] = {"Back", "FTP", "Brightness", "BT Address", "Advanced Settings"};
    display.println(menuItems[selectedVariable]);
  } else {
    const char *advVars[] = {
      "Back", "Num Pixels", "Temp Sensor", "Z1 Percentage", 
      "Z2 Percentage", "Z3 Percentage", "Z4 Percentage", 
      "Z5 Percentage", "Z6 Percentage", "Filter Const", 
      "Spark Const", "Reset"
    };
    display.println(advVars[selectedVariable]);
  }

  display.setCursor(0, 20);
  display.print("Value: ");
  
  if (!inAdvancedTab) {
    // Handle basic variables
    if (selectedVariable == 1) {
      display.print(configData.ftp);
    } else if (selectedVariable == 2) {
      display.print(configData.brightness, 2);
    } else if (selectedVariable == 3) {
      Serial.println("I got here 2");
      scanAndDisplayDevices();
    }
  } else {
    // Handle advanced variables
    if (selectedVariable == 1) {
      display.print(configData.num_pixel);
    } else if (selectedVariable == 2) {
      display.print(configData.temperature_sensor ? "true" : "false");
    } else if (selectedVariable >= 3 && selectedVariable <= 8) {
      // For Z1 to Z6 Percentage
      float *floatVars = &configData.z1_percentage;
      display.print(floatVars[selectedVariable - 3], 2);
    } else if (selectedVariable == 9) {
      display.print(configData.filter_constant, 2);
    } else if (selectedVariable == 10) {
      display.print(configData.spark_constant, 2);
    }
  }

  display.display();
}

void adjustAdvancedVariable(int index, int direction) {
 if (index == 10) {
    return;
  } else if (index == 0) {
    configData.num_pixel += direction;
    configData.num_pixel = max(0, configData.num_pixel); // Ensure non-negative
  } else if (index == 1) {
    configData.temperature_sensor = !configData.temperature_sensor; // Toggle boolean
  } else {
    float *floatVars = &configData.z1_percentage;
    floatVars[index - 2] += direction * 0.01; // Adjust percentages/constants
    floatVars[index - 2] = constrain(floatVars[index - 2], 0.0, 1.0); // Constrain
  }
  
  adjustVariable(); // Refresh the menu with updated values
}
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
void loop() {

  if (!connected && millis()-last_try_connect>100000 && !configData.first_start){
    connected=connecting_bt();
    last_try_connect=millis();
  }
  handleEncoderInput();
  handleButtonPress();
  if (currentMode == NORMAL) {
    // Display temperature and humidity in NORMAL mode
    //noInterrupts();
    if (configData.temperature_sensor){
    status=am2302.read();
    if (status==0){
      humidity = am2302.get_Humidity();
      temperature = am2302.get_Temperature();
    }}
    display.clearDisplay();
    if (mainPage==0){
    writeData(temperature, humidity, 0, 0);
    }else if (mainPage==1){
      writePower(0,0);
    }else if (mainPage==2){
      writeBT(0,0);
    }else{
      mainPage=0;
    }
    display.display();
    showPower();
    
    //interrupts();
  }
}

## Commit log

2025-02-05 Added the pcb
    [SpinningLight-B_Cu.gbr, SpinningLight-B_Mask.gbr, SpinningLight-B_Paste.gbr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]
2025-02-06 Added the casing and its assembly
    [SpinningLight.kicad_pcb]
2025-02-06 This time added the casing
    [Assembly 1 - SOLID (1).stl, Assembly 1 - SOLID (2).stl, Assembly 1 - SOLID (3).stl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]
2025-03-10 Updated the STL Files for the light
    [Assembly 1 - Bottom.stl, Assembly 1 - Lid.stl, SpinningLight.csv]
2025-03-10 improved the pcb by enlarging the holes for the level shifter
    previously, the holes of the level shifter were too small making it effectively a pressfit. It has been improved here.
    [SpinningLight.kicad_pcb]
